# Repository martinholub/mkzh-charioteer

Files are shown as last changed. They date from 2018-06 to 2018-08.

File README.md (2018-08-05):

# CharIoTeer
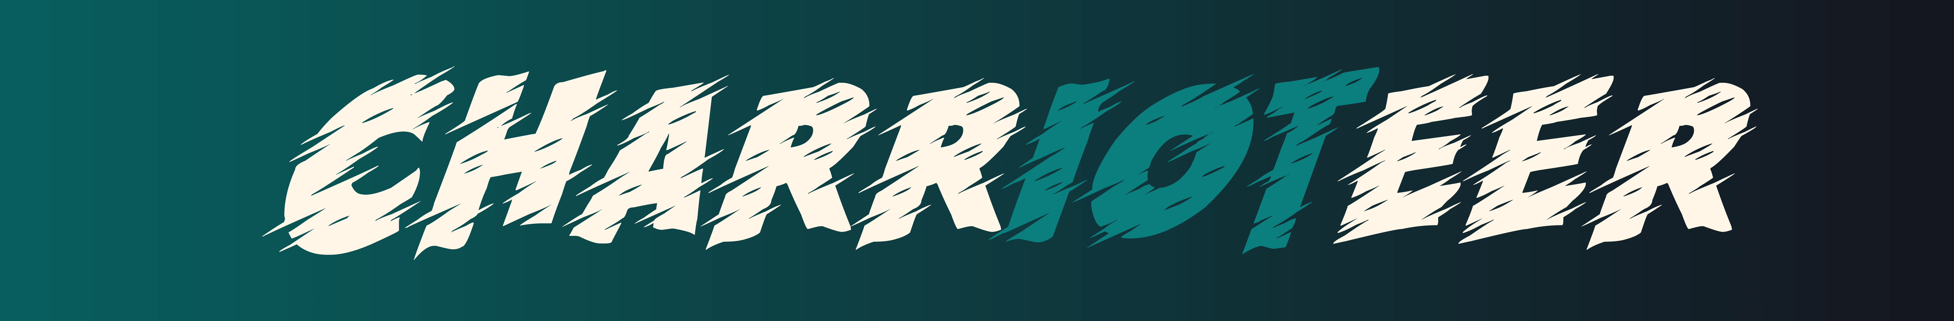
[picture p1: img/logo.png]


### Smart last-mile delivery project @MakeZurich

CharIoTeer is a contribution to the long-standing quest of making delivery smart. By measuring critical indicators of package health (temperature of goods, ambient temperature, humidity, position) together with geographical coordinates. The project provides real-time actionable data for inner-city logistics of high-value shippments (medicines, blood, valuable documents, groceries, cigars,... ).

Check [my blog post](http://www.martinholub.com/eth/code/2018/08/05/MakeZurich.html) on the project.

<!-- and [the project presentation](https://www.slideshare.net/secret/HptLulsGrX1wgX) (credit [Antonios Kouris](https://www.crunchbase.com/person/antonios-kouris#section-overview)). -->

# Building CharIoTeer

Building CharIoTeer is simple and fun! The following sections take you step by step through the process.

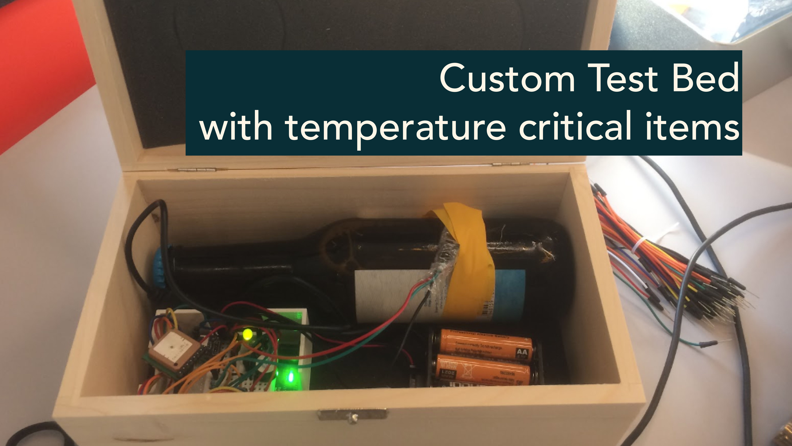
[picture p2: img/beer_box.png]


## Bill of Materials:

* [The Things Network Uno](https://www.thethingsnetwork.org/docs/devices/uno/)
* [ADXL345](https://www.sparkfun.com/datasheets/Sensors/Accelerometer/ADXL345.pdf) Accelerometer
  * alternatively simple [tilt switch](https://learn.adafruit.com/tilt-sensor/using-a-tilt-sensor) may be enough
* [DHT11](http://www.circuitbasics.com/how-to-set-up-the-dht11-humidity-sensor-on-an-arduino/) Temperature and Humidity Sensor
* [Sensirion SHTxx](https://github.com/rac2030/MakeZurich/wiki/SHT31) Temperature and Humidity Sensor
  * alternatively plain [thermistor](http://www.circuitbasics.com/arduino-thermistor-temperature-sensor-tutorial/) will do
* [u-blox PAM-7Q](https://www.u-blox.com/sites/default/files/PAM-7Q_DataSheet_(UBX-13002455).pdf) GPS sensor
* Buzzer, LEDs, Resistors, Jumper Wires, Breadboard, Battery Power Supply
* PLA for 3D printed casing

## Getting Started

Before starting the project, check that your area has [loRaWAN coverage](https://www.thethingsnetwork.org/map). Consider [joining the movement](https://www.thethingsnetwork.org/community) and [building your very own gateway](https://github.com/ttn-zh/ic880a-gateway/wiki). Do some [quick reading](https://www.thethingsnetwork.org/docs/lorawan/) on how LoRaWAN works.

Once your hardware arrives, put it all together:

## Wiring the Arduino

*Note that despite being named The Things Network UNO (TTN Uno), the board is actually a Arduino Leonardo (with a [RN2483](https://www.microchip.com/wwwproducts/en/RN2483) chip). To make this clear, I name TTN Uno TTN Leanardo instead.*

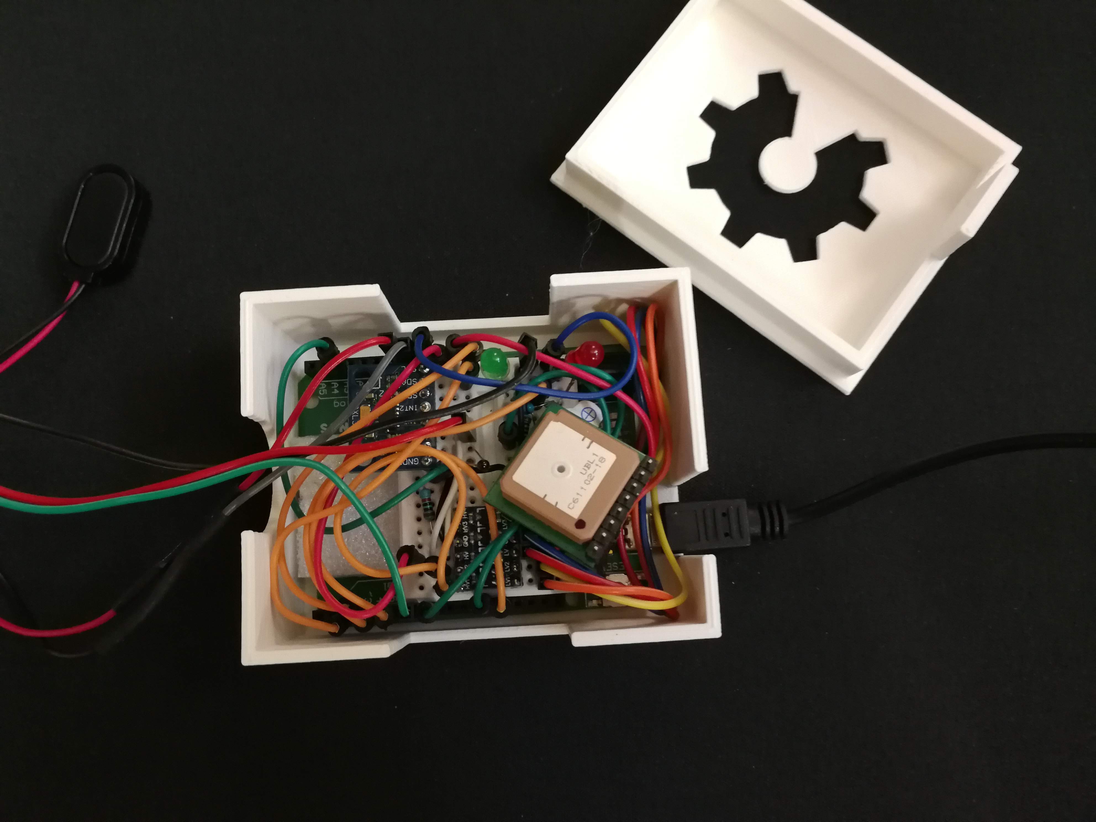
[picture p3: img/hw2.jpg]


**ADXL345** | Arduino UNO | TTN Leonardo
:---:|:---:|:---:
GND | GND | GND
VCC | 5V | 5V
CS | 5V | 5V
SDA | A4 | 2
SCL | A5 | 3

**DHT-11** | Arduino UNO (or TTN Leonardo)
:---:|:---:
\+ | 5V
\- | GND
S | 7

<!---
US100 | Arduino UNO + TTN Leonardo
:---:|:---:
VCC | 5V
GND | GND
Echo | 11
Trig | 10
-->

**u-blox PAM-7Q** | LevelConv | Arduino UNO (or TTN Leonardo)
:---:|:---:|:---:
not connected | HV | 5V
VCC | LV | 3.3V on TTN UNO
TX | LVx <-> HVx | 5
RX | LVx <-> HVx | 13

Device | (+) to board | (-) to board
:---:|:---:|:---:
**red led** | 4 trhu 220R | GND
**green led** | 8 thru 220R | GND
**active buzzer** | 12 | GND thru 100R
**themistor** | 5V | GND thru 10kR and A3

*All connections are identical for Arduino Uno and TTN Leonardo. Polarity for thermistor does not matter.*

## Understanding the Code

#### Practical
You are encouraged to develop the code in [PlatformioIO](https://platformio.org/). If you do so, check the project file `platformio.ini` and make sure it corresponds to your setup. It will handle library dependencies for you. If you are using other IDE (like [Arduino IDE](https://www.arduino.cc/en/Main/Software?)), you may need to install the libraries manually.

#### Sending Data as Bytes

LoRaWAN is a technology that is designed for small volume of transferred data. Each message sent from a device over gateway to a backend is limited to maximally 51 bytes. Preferentially, messages should not exceed 12 bytes as more data per transfer results in longer airtime of each message. Daily airtime per device is limited (see [[limitations](https://www.thethingsnetwork.org/docs/lorawan/limitations.html)] and [[fair access policy](https://www.thethingsnetwork.org/forum/t/limitations-data-rate-packet-size-30-seconds-uplink-and-10-messages-downlink-per-day-fair-access-policy/1300)], therefore messages should not be sent more frequently then every couple of minutes or less.

To reduce the amount of data being sent, I encode each message emitted by the device as bytes. The message is then decoded in a server application by applying reverse mathematical operations.

For example, encoding gographical coordinates to 3 bytes per longitude and 3 bytes latittude may look like this:

``` cpp
void add_buffer_gps(double lat, double lon){

  // offset by 90(180) to make positive and scale to 0..1
  latB = ((lat + 90) / 180.0) * pow(256,3);
  lonB = ((lon + 180) / 360.0) * pow(256,3);

  // byte shifting
  dataBuffer[0] = ( latB >> 16 ) & 0xFF;
  dataBuffer[1] = ( latB >> 8 ) & 0xFF;
  dataBuffer[2] = latB & 0xFF;

  dataBuffer[3] = ( lonB >> 16 ) & 0xFF;
  dataBuffer[4] = ( lonB >> 8 ) & 0xFF;
  dataBuffer[5] = lonB & 0xFF;
  }
```

Another example is encoding of tilt of the device as measured by accelerometer:

``` cpp
void add_buffer_tilt(float Xg_crit, float Yg_crit, int it = 0) {
  // it, position where to start writing to the buffer

  // offset by 2 to assure range -1..1 becomes positive and scale to 0..1
  XgB = (Xg_crit  + 2.0) * pow(256,1) / 4;
  YgB = (Yg_crit + 2.0) * pow(256,1) / 4;

  // each value is just one byte
  dataBuffer[it] = XgB;
  dataBuffer[it+1] = YgB;
  }
```

#### Using Rolling Averages

I want to send message every couple of minutes but our Aurdino with sensors is capable of collecting data at much higher rate. It is advantaegous to send values averaged over several preceding measurements. This makes our measurements more accurate and helps to deal with outliying values. For example for humidity I do that as follows:

``` cpp
#include <RunningAverage.h>
#include <dht11.h> // temperature and humidity sensor
RunningAverage myRA_h(10); // 10 is size of buffer
void setup(){
  myRA_h.clear();
  }

void loop(){
  // ...
  myRA_h.addValue((float)DHT11.humidity);
  // ...
  }
```
#### Obtaining GPS Data

Check out the [working example](https://gitlab.com/mkzh-milesahead/arduino-gps) developed by @njam.

##### Using Smart Delay and Software Serial

The Arduino hardware has built-in support for serial communication on pins 0 and 1 (which also goes to the computer via the USB connection). The native serial support happens via a piece of hardware (built into the chip) called a UART. The Software Serial is used to allow serial communication on other digital pins of the Arduino,

```cpp
static const int RXPin = 13, TXPin = 5;
AltSoftSerial gpsSerial(RXPin, TXPin);

void delay_smart(unsigned long ms) {
  // This custom version of delay() ensures that the gps object is "fed"
  unsigned long start = millis(); // Get current time from board start in ms
  do {
    // wait for data available
    while (gpsSerial.available()) {
      gps.encode(gpsSerial.read());
    }
    // wait extra if needed to fill delay
  } while (millis() - start < ms);
}
```

#### Talking with The Things Network

```cpp
#include <TheThingsNetwork.h>
#include <private_keys.h> // imports appKey and appEUI from external file

#define loraSerial Serial1
#define freqPlan TTN_FP_EU868 // Use european freq plan
#define COUNT_OF(array) (sizeof(array) / sizeof(array[0])) // gets array size

TheThingsNetwork ttn(loraSerial, Serial, freqPlan);
bool is_connected = false;
uint8_t dataBuffer[12] = {0}; // uint8_t is byte, buffer can hold 12 bytes

void send_ttn_message(uint8_t* data, size_t data_size, port_t prt = 1) {
    if(is_connected){
      ttn.sendBytes(data, data_size);// sizeof(data)
    } else {
      Serial.print("ttn message: ");
      uint8_t i = 0;
      for (i = 0; i < data_size; i++){ // prints byte message in HEX encoding
        if (data[i] < 16) {
          Serial.print("0");
          Serial.print(data[i], HEX);
        } else {
          Serial.print(data[i], HEX);
        }
      }
      Serial.println("");
    }
}

void setup(){
  Serial.print("--- TTN STATUS ---"); ttn.showStatus();
  ttn.provision(appEui, appKey);
  is_connected = ttn.join(10); // try to connect up to 10 times
  if (!is_connected){
    Serial.print("Join to TTN failed.");
  }
}

void loop(){
  // ...
  // Messaging the TTN Application
  if (iteration % send_per == 0){ // send only infrequently
    send_ttn_message(dataBuffer, COUNT_OF(dataBuffer));
  }
  // ...
}
```

More can be found on the [Quick Start](https://www.thethingsnetwork.org/docs/devices/uno/quick-start.html) site for the TTN Uno (Leonardo) device.

## Printing the Case

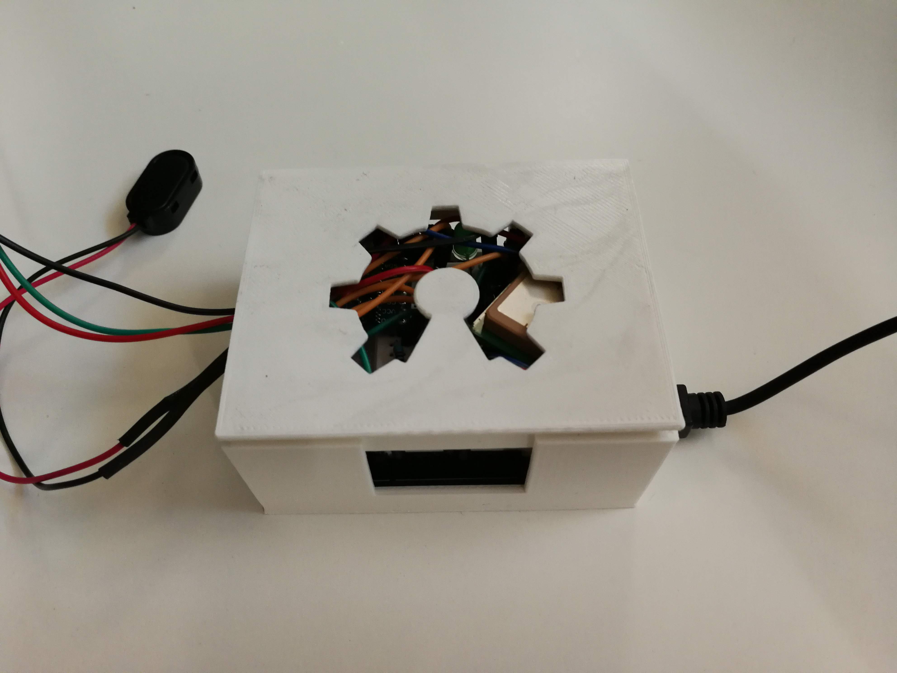
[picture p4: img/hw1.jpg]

I wanted to have a nice casing for the project to work as tight protective enclosure and to make it all together look neat. To design the case (starting from a [template](https://www.thingiverse.com/thing:78032)) I used [OpenSCAD](http://www.openscad.org/). I sliced the `stl` files to `gcode` using [CURA](https://ultimaker.com/en/products/ultimaker-cura-software) and printed them on a 3D printer from [Teil3](https://www.teil3.ch/shop/3d-drucker.html). You will find the design in `scad` file in `hw` folder for you to adjust and play with.

<!-- mail guy from tel3d ..... get cura settings! -->

## Receiving and Decoding Payloads

Once the data was emitted by the [RN2483](https://www.microchip.com/wwwproducts/en/RN2483) chip, received by usually [multiple](https://www.thethingsnetwork.org/docs/network/architecture.html#de-duplication-broker)) gateways it is handed over to the backend server application. We used [The Things Network Console](https://console.thethingsnetwork.org/) to create and manage such applciation inlcuding its `decoder` , `validator` and `converter` functions.

For example the `decoder` function for geographical coordinates and for temperature looks as following (compare with encoding on Arduino above):

```js

function Decoder (bytes, port) {
  var decoded = {}
  if (port === 1) {
    if (bytes.length === 10) {
      var lat = bytesToInt(bytes.slice(0, 3)) / Math.pow(256, 3) * 180 - 90
      var lon = bytesToInt(bytes.slice(3, 6)) / Math.pow(256, 3) * 360 - 180
      if (lat !== 0 && lon !== 0) {
        decoded['lat'] = lat
        decoded['lon'] = lon
      }

      var tiltx = bytesToInt(bytes.slice(10, 11)) / Math.pow(256, 1) * 4 - 2
      decoded['tiltx'] = tiltx
      var tilty = bytesToInt(bytes.slice(11, 12)) / Math.pow(256, 1) * 4 - 2
      decoded['tilty'] = tilty
    }
  }
  return decoded
}

function bytesToInt (bytes) {
  var integer = 0
  for (var n = 0; n < bytes.length; n++) {
    integer += bytes[n]
    if (n < bytes.length - 1) {
      integer = integer << 8
    }
  }
  return integer
}
```

Here is a sample of datapoint:

```json
{"_id": "5b377f54e4d28c0006c1ab93",
  "deviceId":"ttn-uno",
  "receivedAt":"2018-06-30T13:02:12.565Z",
  "metadata":{
    "time":"2018-06-30T13:02:12.339076452Z",
    "frequency":868.1,
    "modulation":"LORA",
    "data_rate":"SF7BW125",
    "airtime":66816000,
    "coding_rate":"4/5",
    "gateways":[
      {"gtw_id":"eui-0000024b080310b1",
        "timestamp":628068507,
        "time":"2018-06-30T13:02:11.414067Z",
        "channel":0,
        "rssi":-117,
        "snr":1.5,
        "rf_chain":1,
        "latitude":47.37787,
        "longitude":8.53909,
        "altitude":433
      }
    ]
  },
  "dist":0,
  "speed":0,
  "temp-inside":16.99981689453125,
  "temp-outside":23.09722900390625,
  "tiltx":0.1875,
  "tilty":-0.203125
}
```
## Storing and Visualizing Data

The server application was developed by [@njam](https://github.com/njam). The full source code is available at the [project's gitlab](https://gitlab.com/mkzh-milesahead/ttn-milesahead). The visalizations are available [here](https://ttn-milesahead.herokuapp.com/).

Here is a sample visualization showing geographical coordinates as dots color-coded by temperature measured by DHT11 sensor.

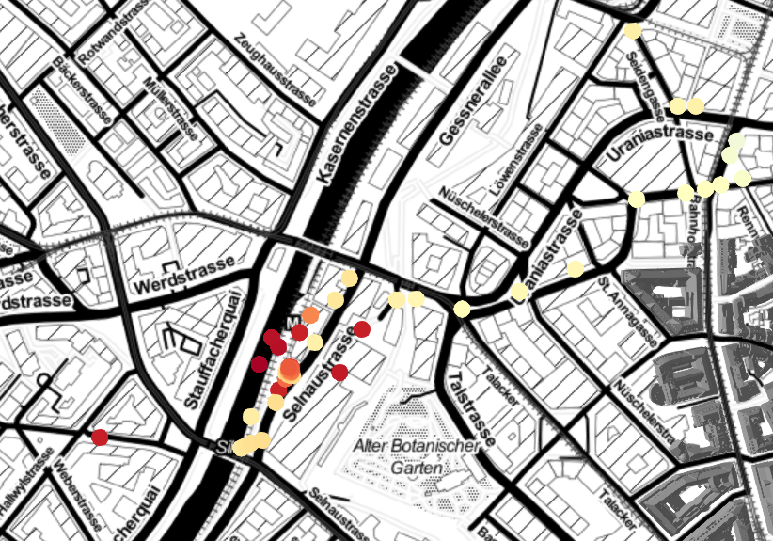
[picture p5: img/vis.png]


## Remarks
* If you decide to use SHTxx sensor together with ADXL345 acceloremeter, you will have them share I2C bus. This is [not a problem](https://www.bluedot.space/tutorials/how-many-devices-can-you-connect-on-i2c-bus/) as long as the devices will [have dfferent addresses](http://www.learningaboutelectronics.com/Articles/Multiple-I2C-devices-to-an-arduino-microcontroller.php).
* If you want to deploy the device for real-world application, consider using LoRa capable low-power microcontroller like [MSP430](https://platformio.org/lib/show/374/armapi), [muRata LoRaWan module](https://www.murata.com/en-sg/products/lpwa/lora) or [MKR WAN 1300](https://store.arduino.cc/mkr-wan-1300)

## References
* [MakeZürich](https://makezurich.ch/about/)
* [The Things Network Community in Zürich](https://www.thethingsnetwork.org/community/zurich/)
* [Post kauft Logistik Startup notime](https://www.startupticker.ch/en/news/march-2018/post-kauft-logistik-startup-notime) (German)

## Team
* Martin Holub ([web](http://www.martinholub.com/about/))
* Reto Kaiser ([@njam](https://github.com/njam))
* Antonios Kouris ([crunchbase](https://www.crunchbase.com/person/antonios-kouris#section-overview))
* Charilaos ([@tsarouch](https://github.com/tsarouch))

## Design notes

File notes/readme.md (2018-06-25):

# Follow-up notes for meeting #1

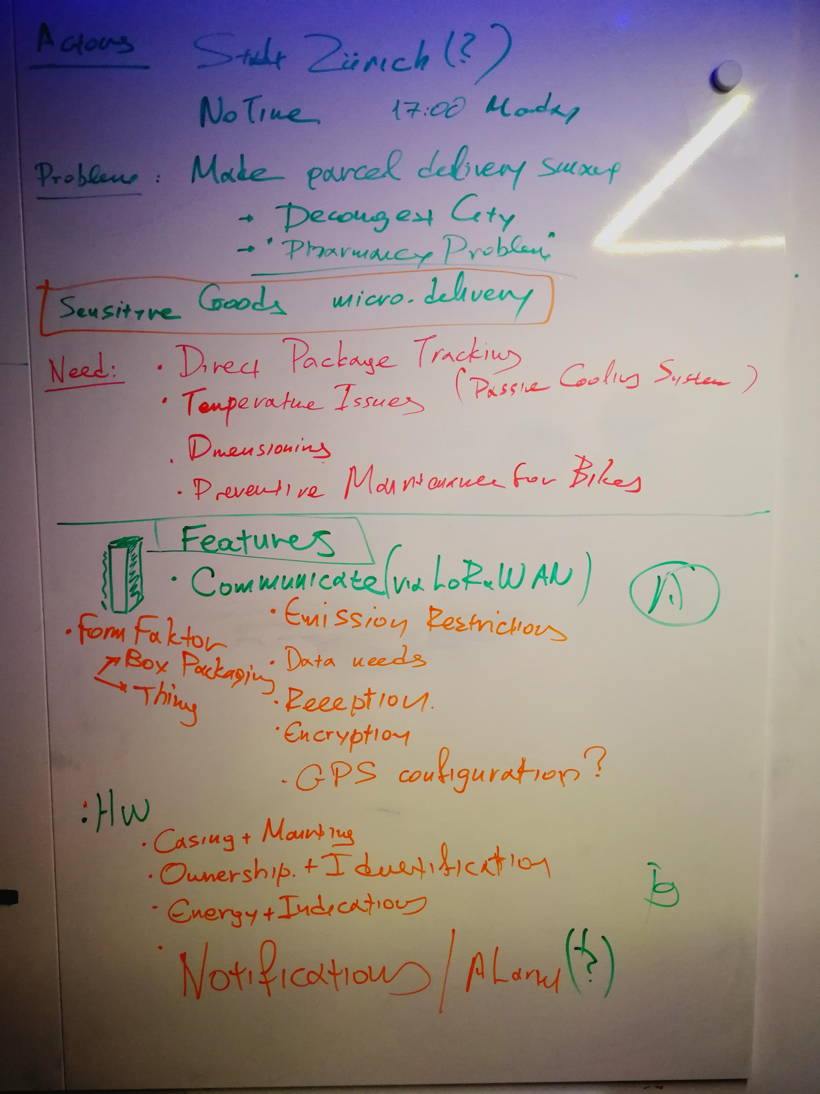
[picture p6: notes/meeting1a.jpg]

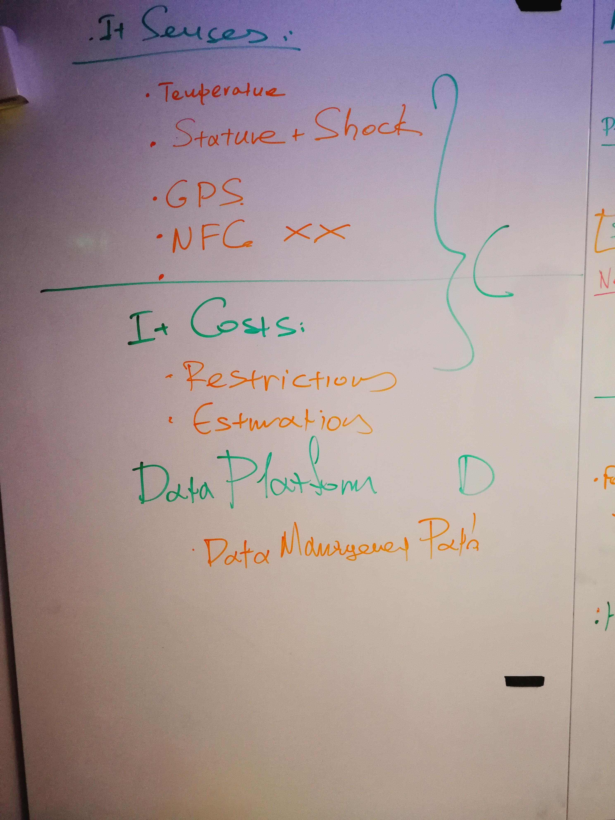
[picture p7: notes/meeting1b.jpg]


# Features

## Communication (Martin)

TODO: suck out info from here: https://www.thethingsnetwork.org/docs/lorawan/

#### Requirements
Note: sensors have errors - can [round](https://www.thethingsnetwork.org/docs/devices/bytes.html#2-round) and save on data transmission
+ Tilt: 
  + 1/0 ... Ok/Bad
  + 0.xx for X and Y axes -> 2 bytes
+ Temp:
  + 1/0 ... Ok/Bad
  + xx.x ... float with 1 decimal -> 1 byte (?)
+ Humidity:
  + 1/0 ... Ok/Bad -> 1 bit
  + xx %  -> 1 byte
+ US sensor:
  + xx for 3 axes -> 3 bytes
+ [GPS coords](https://www.thethingsnetwork.org/forum/t/best-practices-when-sending-gps-location-data/1242):
  + see the link for detailed limitations and tips

#### Limitations
+ [Limitations](https://www.thethingsnetwork.org/docs/lorawan/limitations.html)

[Limitations: data rate, packet size, 30 seconds uplink and 10 messages downlink per day Fair Access Policy](https://www.thethingsnetwork.org/forum/t/limitations-data-rate-packet-size-30-seconds-uplink-and-10-messages-downlink-per-day-fair-access-policy/1300)
  + 30 seconds air-time per device per day. For 10 bytes of payload, this translates in (approx.):
    + 20 messages per day at SF12
    + 500 messages per day at SF7
  + Downlink bandwidth is even more restricted (10 msg per day) = you can’t send all messages as ‘confirmed uplink’
  - Payload should be as small as possible. A good goal is to keep it under 12 bytes. ...
  - Interval between messages should be in the range of several minutes, ...
If your application requires more bandwidth, think of another solution
  + In short LoRa excels at rare and small messages from a device that can live independetly for years. Does this fit our application?
  
#### The Network
> Each transmission blocks the receivers of a gateway for some time, it is better to send messages in a shorter time [source](https://www.thethingsnetwork.org/docs/network/architecture.html#downlink-configuration-router).

> LoRaWAN is a long-range radio protocol, making it likely that the message is received by more than one gateway [source](https://www.thethingsnetwork.org/docs/network/architecture.html#de-duplication-broker). Backend then must perform some de-duplication to obtain unique message. The information from duplictaes can be used to get location of the emitting device. Required de-duplication time is about 200ms.

> The frame counter in LoRaWAN messages is a security measure used to detect replay attacks. After validating the MIC, the Broker checks if the Frame counter is valid. As frame counters can only increase, a message with a frame counter that is lower than the last known frame counter should be dropped. [sourcce](https://www.thethingsnetwork.org/docs/network/architecture.html#frame-counter-check-broker)

`decoder`, `converter`, `validator` functions are used [to interpret](https://www.thethingsnetwork.org/docs/network/architecture.html#payload-conversion-handler) message on the handler side.

#### Security
> LoRaWAN enforces using AES 128-bit message integrity checks and payload encryption. Payloads are fully encrypted between the Node and the Handler component of the backend. This means you can choose to operate your own private Handler and have real end-to-end encryption. [source](https://www.thethingsnetwork.org/docs/network/security.html). The metadata is not encrypted.

#### Devices

> Technically, you can send 51 bytes. But, the more bytes you’ll send, the more airtime the package will cost you. [source](https://www.thethingsnetwork.org/docs/devices/bytes.html#how-many-bytes-can-i-send)

[How to send decimals?](https://www.thethingsnetwork.org/docs/devices/bytes.html#how-to-send-decimals)
[How to send multiple numbers?](https://www.thethingsnetwork.org/docs/devices/bytes.html#how-to-send-multiple-numbers)
[How to send big numbers?](https://www.thethingsnetwork.org/docs/devices/bytes.html#how-to-send-big-numbers)
How to send text? The short answer is: don’t.

> Devices should perform join operations the less possible in their lifetime. The LoRaWAN specifications warn especially against systematic rejoin in case of network failure. A device should keep the result of an activation in permanent storage if the device is expected to be turned off during its lifetime. [source](https://www.thethingsnetwork.org/docs/devices/bestpractices.html#otaa-best-practices)

#### Practical Bits and Pieces

Transmitted data:
  + Can get [some metadata](https://www.thethingsnetwork.org/docs/network/architecture.html#gateway-protocol-translation-routerbridge) from gateway message:
    + signal strength (RSSI) and signal-to-noise ratio (SNR)
  + Message has "port" field. Can use to switch between incoming measurements

+ Neither LoRa nor GPS will be able to communicate from a box
  + already indoor coverage is a problem
  + we may want to prototype from inside a box?
  + No guarantee on acceptance of message

+ Should be able to switch network providers
  + e.g. tnn > fallback to loriot > fallback to swisscom
  + provider may limit number of messages (Swisscom... 10/day)
  + this may be possible from platform.makezurich.ch
  
### Questions
+ Can GPS talk from a box? Where it needs to be?
+ What sensors does the FMLR TrackerTwo have?
+ How often do we need to transmit data? How often we can? (LoRaWAN)

### References:

[TTN-Learn-Network](https://www.thethingsnetwork.org/docs/network/architecture.html)

## Hardware (Reto)

### Accelerometer
https://learn.adafruit.com/adafruit-bno055-absolute-orientation-sensor?view=all
https://www.aliexpress.com/item/BNO055-CJMCU-055-Intelligent-9-Axis-Attitude-Sensor-precision-Accelerometer-gyroscope-magnetic-sensor-module-for-arduino/32842626275.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
https://www.allaboutcircuits.com/projects/bosch-absolute-orientation-sensor-bno055/
https://www.davidpilling.com/wiki/index.php/BNO055

#### Notes
To solder or not to solder [the barrel](https://forums.adafruit.com/viewtopic.php?f=19&t=118110)
> The object resembling a tilt switch is probably a 32.768 kHz quartz crystal. It's optional. You can send a command to the BNO telling it to use either its lower-accuracy internal oscillator, or its higher-accuracy crystal oscillator.

SDA/SCL pins on [Leonardo and Uno](https://arduino.stackexchange.com/a/160)

https://learn.adafruit.com/adxl345-digital-accelerometer/programming

## Sensing (Antonias)

## Dataplatform (Charilaos)

console.thethingsnetwork.org
platform.makezurich.ch

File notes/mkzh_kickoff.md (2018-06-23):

# Real Time Occupancy Rate
Real time data on all vehicles (bus, trams, boats?)
# City forest visitiors
Lot of entry points to big area
No concrete idea how many people come in
- Where people tend to stay/linger
- Which roads are used more / is there more roads? Trend detection
- Conflict detection
- Resources allocation justification
- Mind people/data security!
PubliBike
- No docking station
- Bike is wirelessly connected to the station point
- Lot of bikes lausanne
- Need to track bikes that are left behind, possibly without battery
- Can be unlocked with any RFID card
- Must be easy to install
- Dont use bike battery
- better than 50 m accuracy
- has slack
Coquering the last mile
- not presented
Teachers calling (stakeholder not present)
- Needs to be silent
- Students cant use cellphones, teacher should not be focusing on cellphone
(could use that older people hear at different freq)
- would be nice if the person has some GPS location 
Distribution challenge (ewz)
- power failure at homes --- they cannot see it
- customers must conntact help center
- putting sensor to distribution cabing may be an option.
- only 2000 cabins in ZH (solution should scale/ 100chf per cabin maximum)
- every 10 days there is a power outage ... what about some stats
  - civil engineering work (shoould alert the workers), svere weather
- space is limited

Platfomr provided by HiveMide
  - Some sensors from Sensirion

platfrom.makezurich.ch
now.makezurich.ch
Teil3 ... 3D printers
GoogleDeveloperGroup (Michelle)

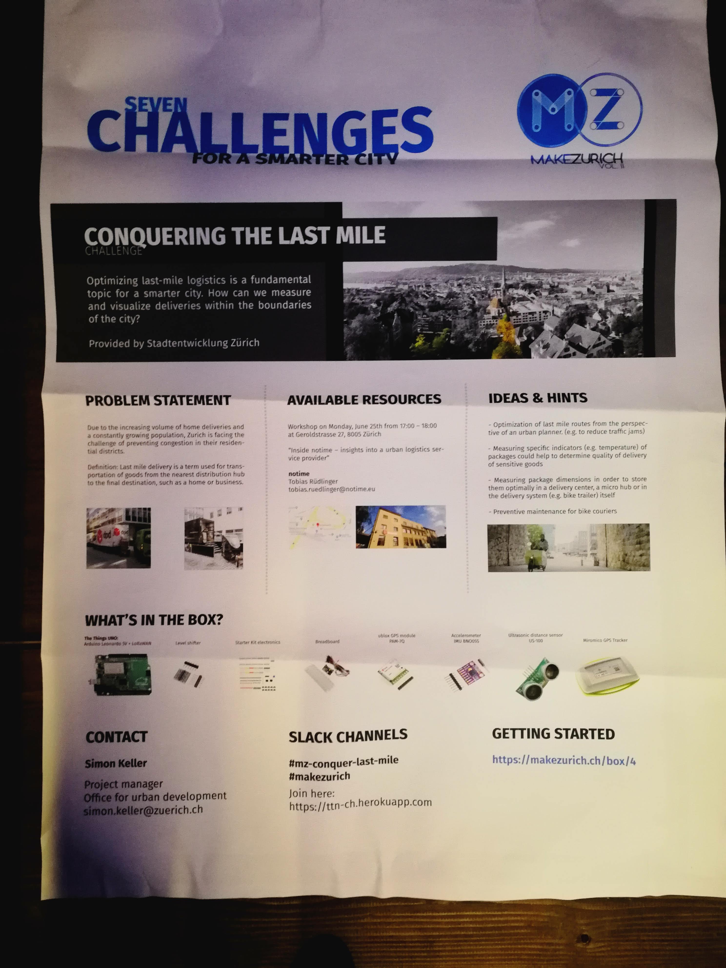
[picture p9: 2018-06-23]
notes/challenge_poster.jpg

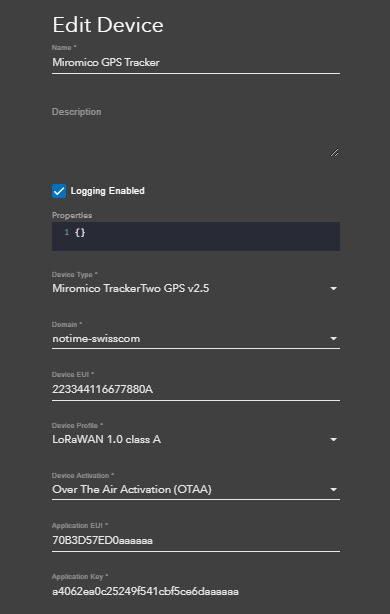
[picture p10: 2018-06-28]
docs/GPSTracker_details.png

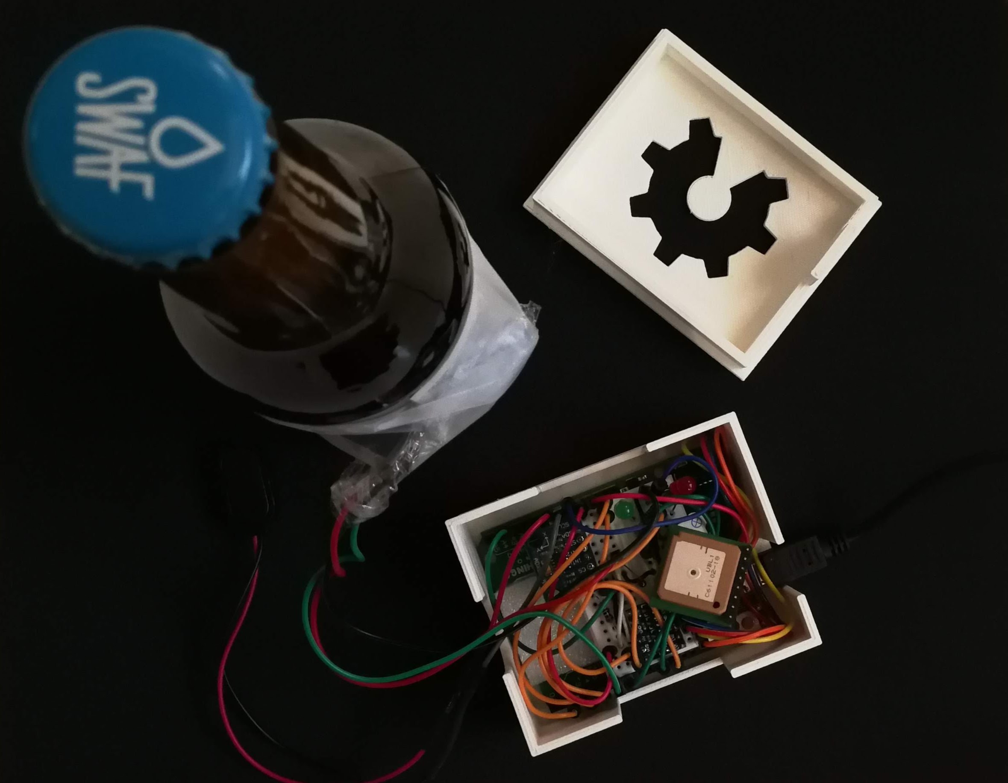
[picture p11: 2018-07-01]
img/hw_and_beer.jpg

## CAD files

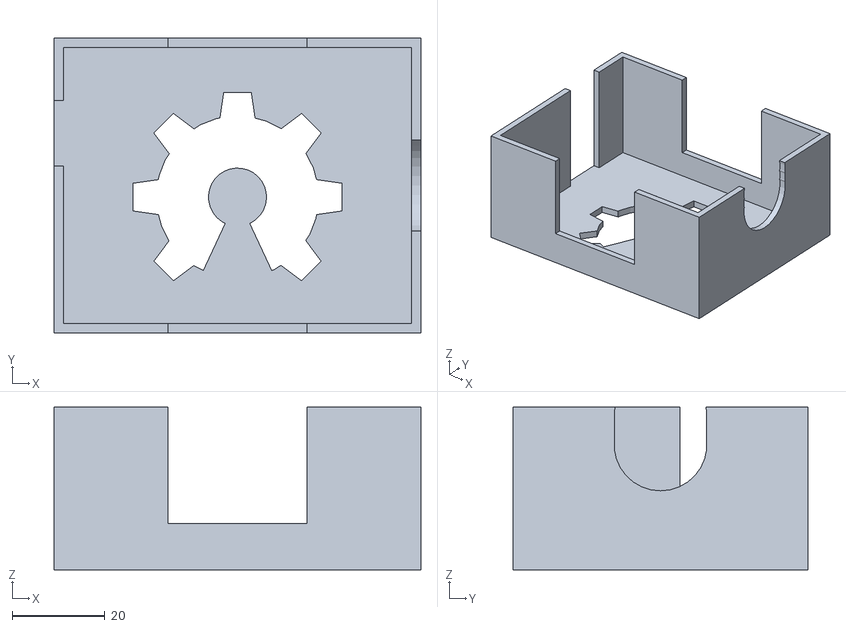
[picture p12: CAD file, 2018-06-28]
hw/arduino_leonardo_box_h35mm_m40mm_v40_notime_boxx.stl
79.0 x 63.5 x 35.0

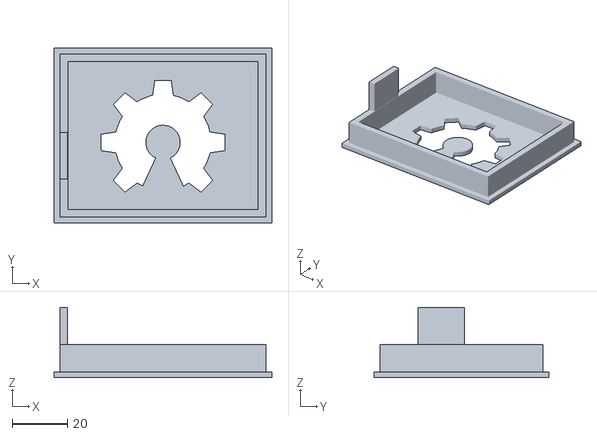
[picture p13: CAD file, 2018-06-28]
hw/arduino_leonardo_box_h35mm_m40mm_v40_notime_deckel.stl
79.0 x 63.5 x 25.5

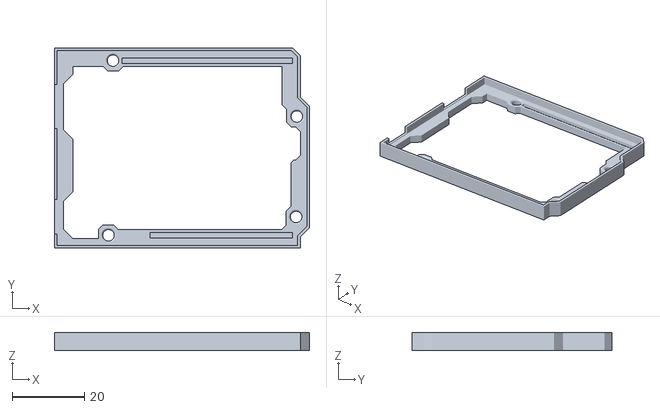
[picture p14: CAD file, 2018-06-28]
hw/bumper.stl
70.5 x 55.2 x 5.08

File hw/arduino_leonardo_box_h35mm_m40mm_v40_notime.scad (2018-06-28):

// Arduino Box with additional space for electronics
// Leonardo form  
//
// V3.1 - little bigger usb hole
// V4.0 reworked, V4.0a correction deckelweite
//
// (C)2013 Nischelwitzer Alexander nischelwitzer@gmail.com
// ----------------------------------------------------------- 

use<write/write.scad>

// ------------------------------------------- breadboard size

card_length = 69.0;
card_width  = 53.5;

// ------------------------------------------- 

box_do      =  0;  // 1 if additional box is used

box_height  = 35;
box_more    = 40;
shifter     = 10;

// ------------------------------------------- 

wall        =  2;
space       =  0.3;
dummy       =  1; // not used

deckel      = 12;

name_it     =  0;  // write some text
form_it     =  0;  // inside form for leonardo

// ------------------------------------------- 
do_light = 1; // print with lot of holes
do_easy = 1; // print w/out any support
// ################################################################
// ################################################################

// translate([0,card_width+shifter-10,0]) deckel();
translate([0,0,0])                     boxx();
translate([0,-(card_width+20),0])      deckel_innen();

// ################################################################
// ################################################################

module boxx() {
  difference() 
  {
    union()  
    {  
      color([1,0,0,1])  translate([0, 0, 0]) 
        cube([card_length+shifter,card_width+shifter,box_height]); 

      color("blue") translate([card_length+shifter-box_do*wall, 0, 0]) 
        cube([box_do*box_more,card_width+shifter,box_height]);
 	}

    translate([wall, wall, wall]) 
      cube([card_length-2*wall+shifter,card_width-2*wall+shifter,box_height]); 
    translate([card_length+shifter+wall-box_do*wall, wall, wall]) 
      cube([box_do*box_more-2*wall,card_width-2*wall+shifter,box_height]); 
   
   // usb connector
   if (do_easy != 1) { // will use support
       translate([-9,36,2]) cube([17,14,10]); 
   } else if (do_easy == 1) { // hole all way to the top to avoid support
       translate([-9,36,2]) cube([17,14,box_height+shifter]);
       }
   

   // connector hole inside
   if (box_do == 1)
   {
     translate([card_length,(card_width+shifter)/2,box_height-deckel/2]) 
       rotate([0,90,0]) cylinder(r=17,h=20);  
     translate([card_length,wall,box_height-deckel-2]) 
       cube([20,card_width+shifter-2*wall,deckel*2]);
   }

   // connector hole outside
   for (a =[8,5,2]){ // repeat couple of times to get nice transition
       translate([card_length+box_do*box_more,(card_width+shifter)/2,box_height-a]) 
     rotate([0,90,0]) cylinder(r=10,h=20); 
       }
    
   // pefuse with holes where possible
   if (do_light == 1) {
       // Add rectangular "windows" on sides
       c_x = 30;
       c_y = 1/3 * c_x;
       c_z = c_x;
       translate([card_length/2-c_x/2 + shifter/2,-c_y/2,box_height/2-c_z/4]) cube([c_x,c_y,c_z]);
       translate([card_length/2-c_x/2 + shifter/2,card_width+shifter/2-c_y/2 + shifter/2,box_height/2-c_z/4]) cube([c_x,c_y,c_z]);
       
       // Add same connector hole also on front side
       if (do_easy != 1){ // Don't over do it and avoid collision of shapes
           for (a =[8,5,2]){
           translate([-shifter,(card_width+shifter)/2,box_height-a])
           rotate([0,90,0]) cylinder(r=10,h=20); 
           }
       }
   
       // logo open hardware
       translate([(card_length+box_do*box_more)/2+shifter/2,(card_width+shifter/2)/2, -10]) rotate([0,0,0]) 
       linear_extrude(height=20) import(file="./oshw_logo_2d.dxf", scale=0.25);
   }
   }
  if (form_it == 1) // Include board holder
  translate([card_length/2+shifter/2,card_width/2+shifter/2,wall])  
    import("bumper.stl");
}


// ################################################################

module deckel() {
   // not used
  difference() 
  {
    union()  
    {   
      color([0,1,0,1])  translate([0-wall-space, shifter*2-wall-space, 0]) 
        cube([card_length+shifter+box_do*box_more+2*(wall+space)-box_do*wall,
              card_width+shifter+2*(wall+space),deckel]); 
	}

    translate([0-space, shifter*2-space, wall]) 
      cube([card_length+shifter+box_do*box_more+space*2-box_do*wall,
            card_width+shifter+space*2,deckel]); 
  }

  if (name_it == 1) translate([wall*4, wall*4+shifter*2, wall]) rotate([0,0,0]) 
    write("Nischelwitzer",t=2,h=8.0,center=false,font="letters.dxf");
}

// ################################################################

module deckel_innen() 
{
  difference() 
  {
    union()  
    {   
      color([0,1,1,1]) translate([0, 0, 0]) 
      cube([card_length+shifter+box_do*box_more-box_do*wall,
            card_width+shifter,wall]); 

      color([0,0,1,1]) translate([wall+space/2,wall+space/2, 0]) 
      cube([card_length+shifter+box_do*box_more-space-2*wall-box_do*wall,
           card_width+shifter-space-2*wall,deckel]);
    
    // Create overlap from top to hide some of insides
    if (do_easy==1){
        mltplier = 1.2;
        color([0,0,1,1]) translate([wall+space/2,card_width+-(1-mltplier)*14-36-space-2*wall,2]) cube([wall+2.5*space,mltplier*14,2*wall+deckel+box_height/2-10]);
        }
	}
    // Create rim by substracting inner cube
    translate([2.5*wall, 2.5*wall, wall])
      cube([card_length+shifter+box_do*box_more-5.0*wall-box_do*wall,
            card_width+shifter-5*wall, deckel]);
    
    // logo open hardware
    // pos mitte
    translate([(card_length+box_do*box_more)/2+shifter/2, (card_width+shifter/2+shifter*name_it)/2, -10]) rotate([0,0,0]) 
    linear_extrude(height=20) import(file="./oshw_logo_2d.dxf", scale=0.25);
    
    // pos over leonardo
    // translate([(card_length+box_do*box_more)/2+shifter/2-30, 0, -10]) rotate([0,0,0]) 
    //   linear_extrude(height=20) import(file="./oshw_logo_2d.dxf", scale=0.3);
  }

  if (name_it == 1) // write name on the inside of the deckel
  translate([wall*4, wall*4, wall]) rotate([0,0,0]) 
    write("milesahead",t=2,h=9.0,center=false,font="letters.dxf");
  // outside would be also nice but difficult to print
}
// ################################################################

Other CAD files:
hw/oshw_logo_2d.dxf

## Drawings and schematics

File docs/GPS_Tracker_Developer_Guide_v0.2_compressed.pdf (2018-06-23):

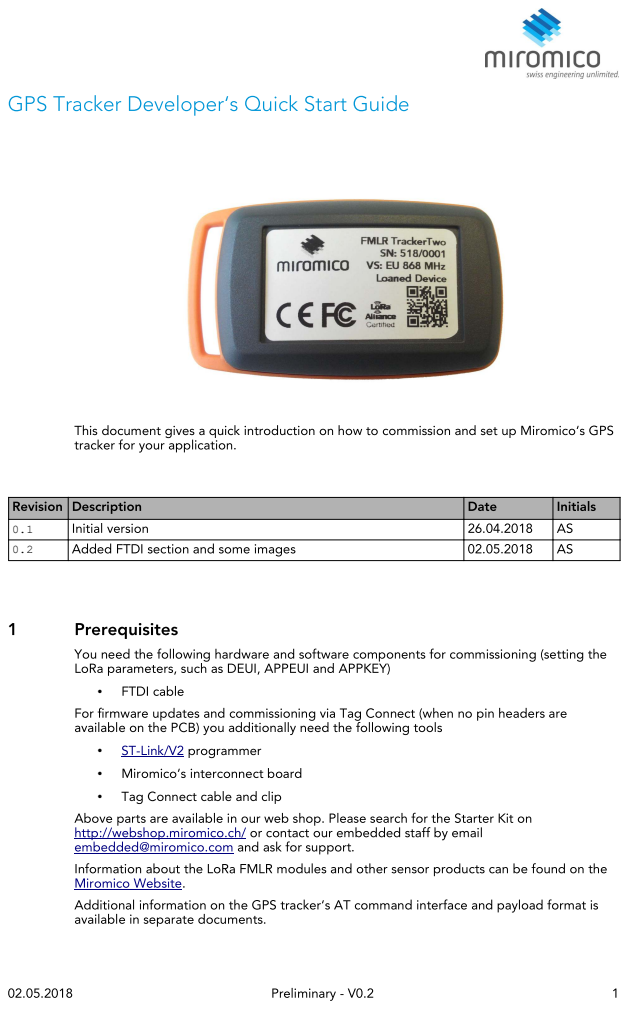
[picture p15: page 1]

0.1
0.2

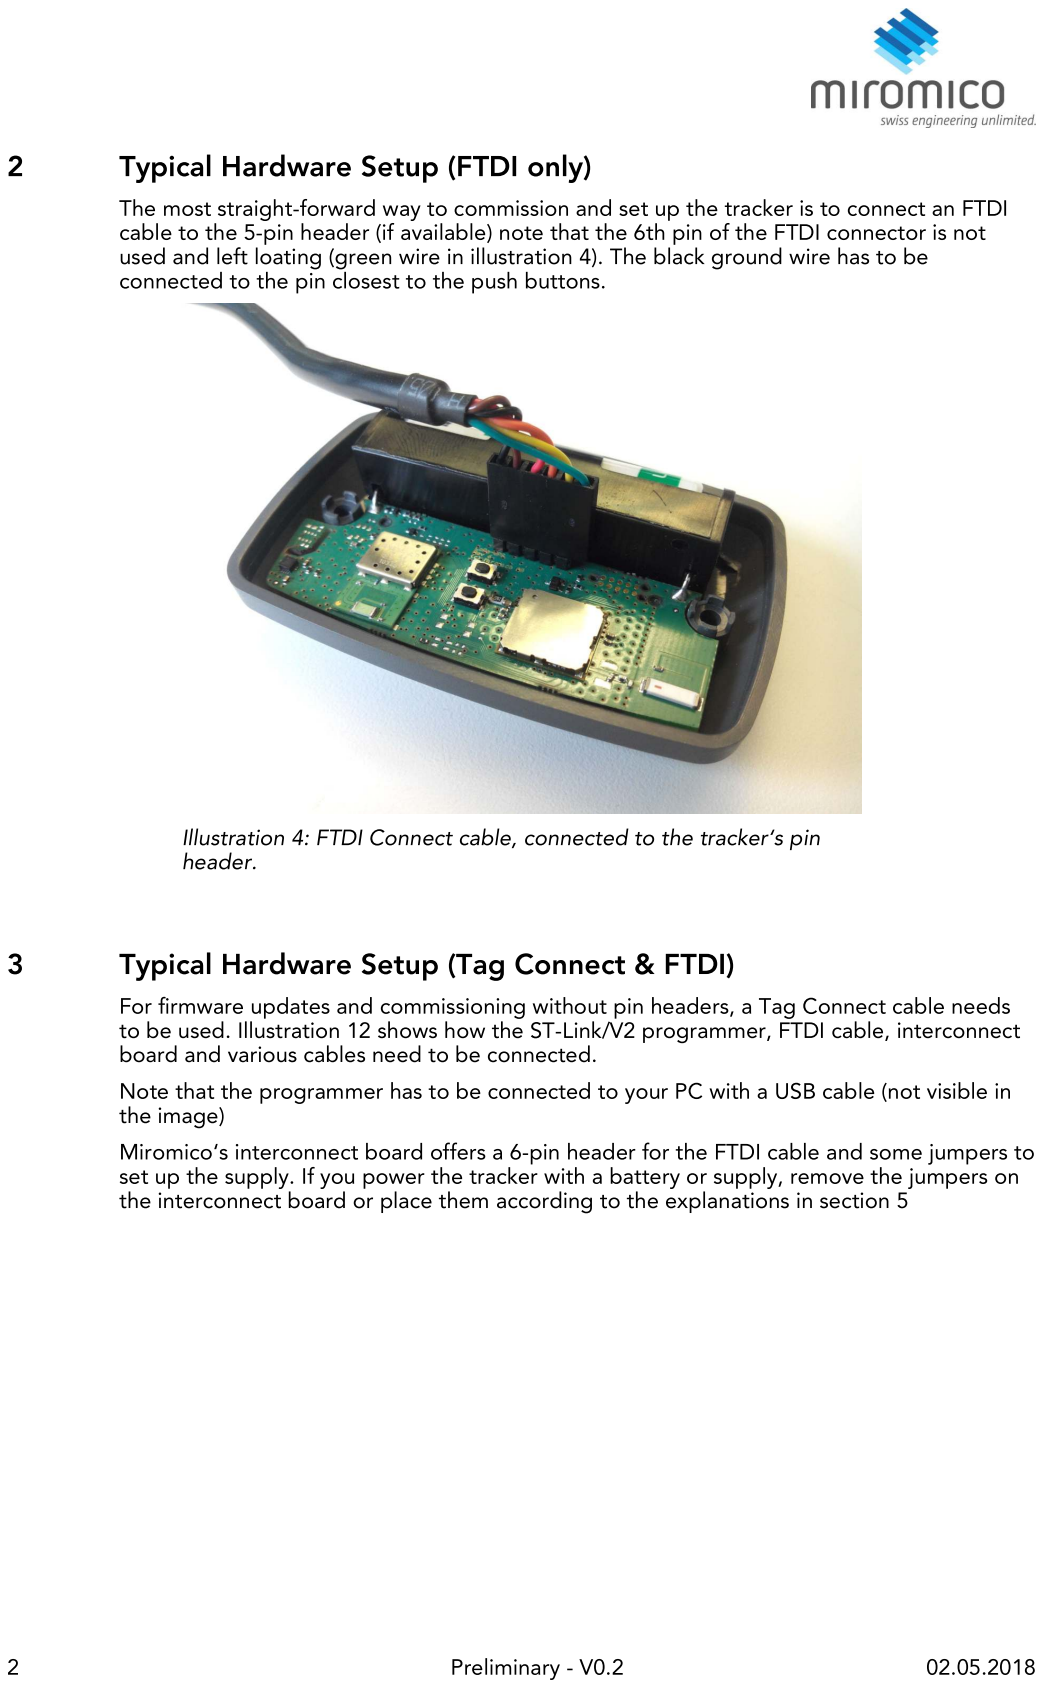
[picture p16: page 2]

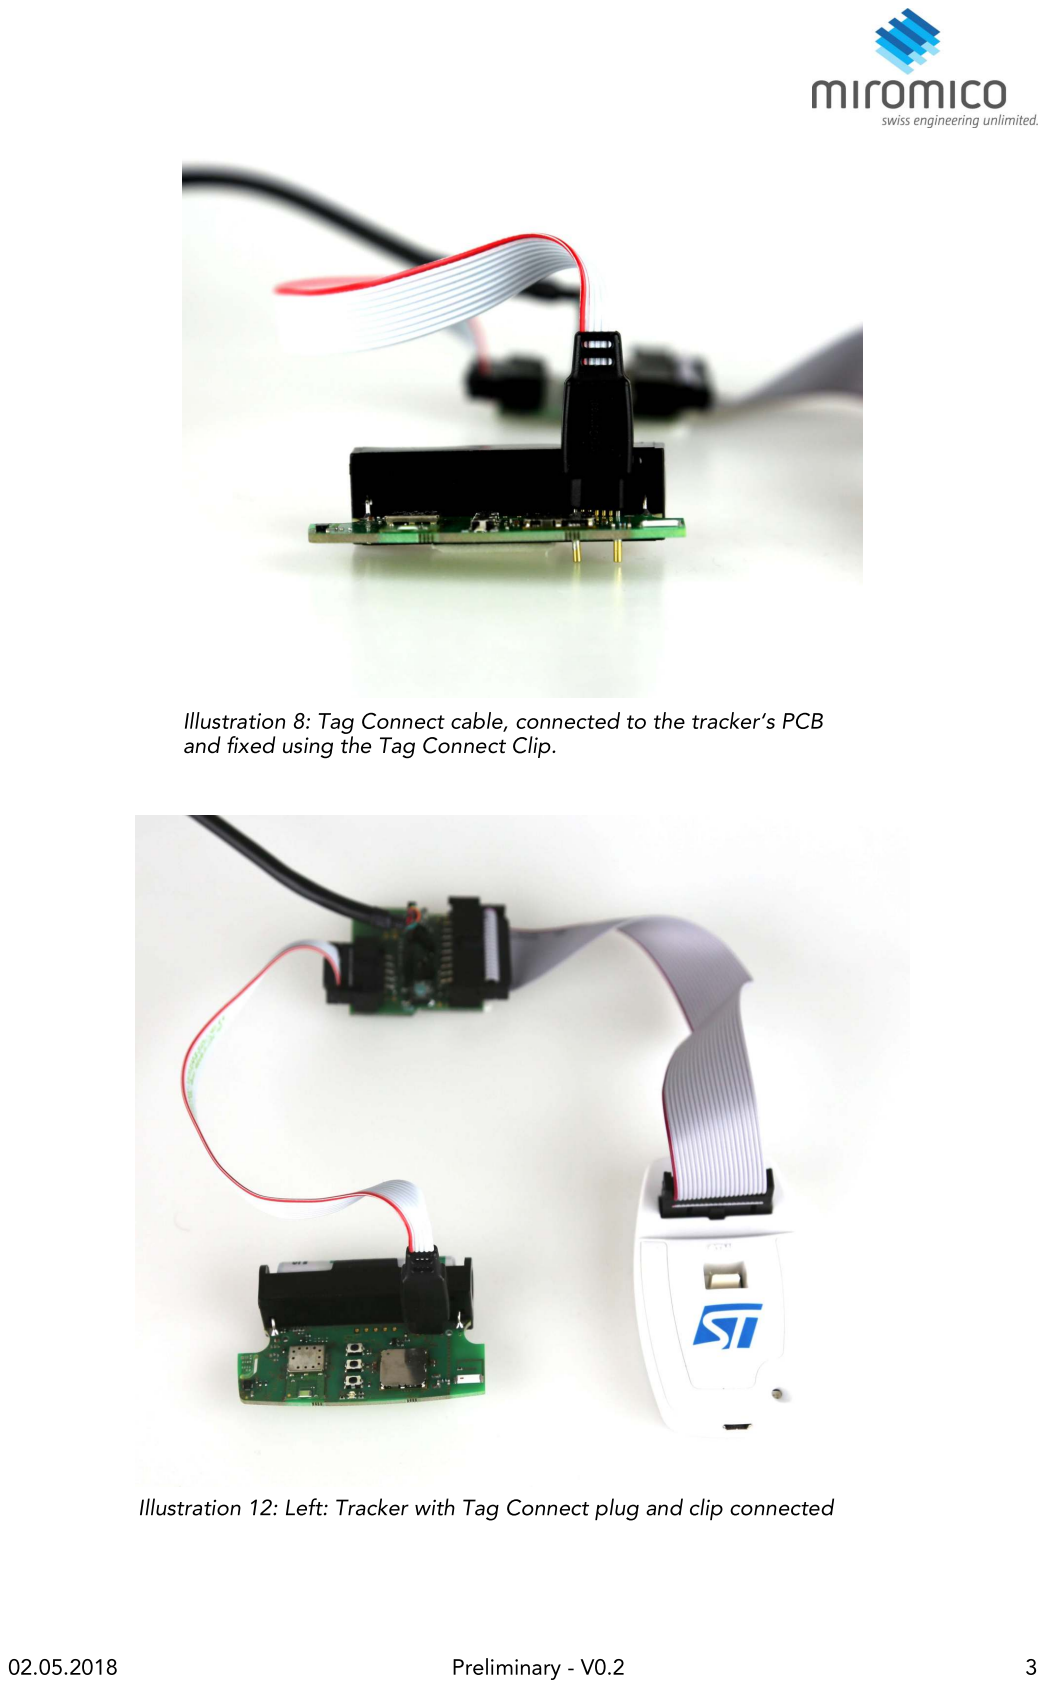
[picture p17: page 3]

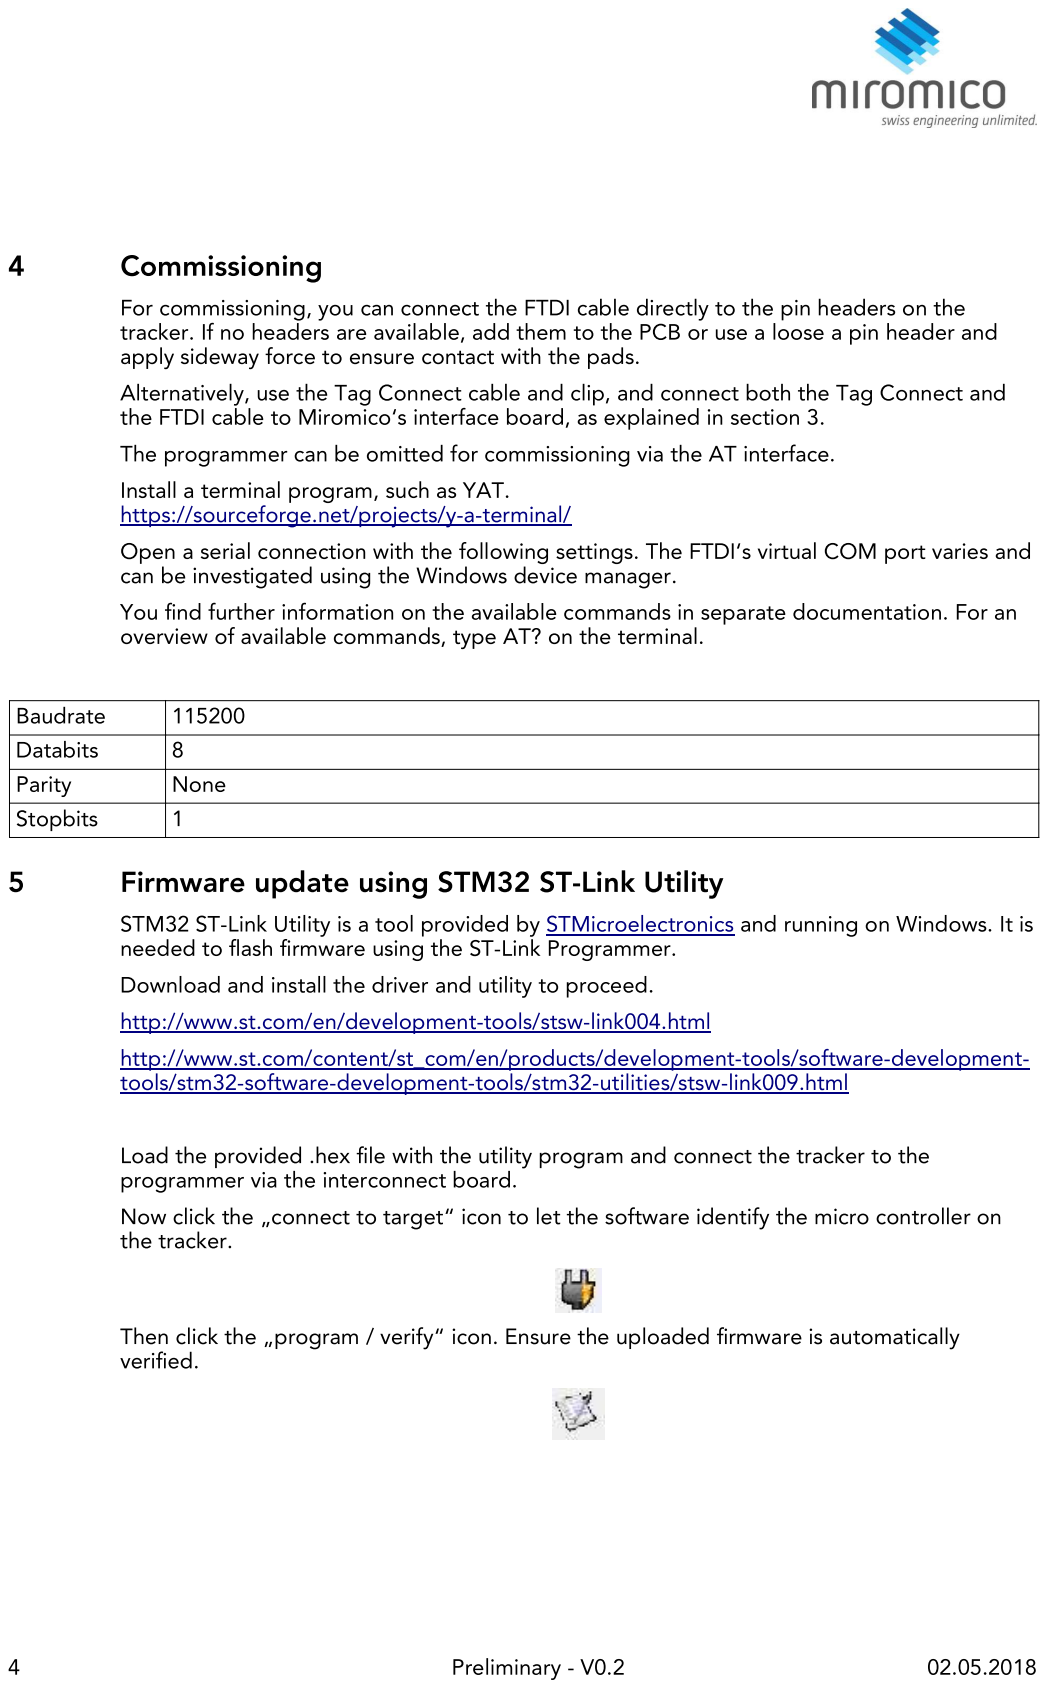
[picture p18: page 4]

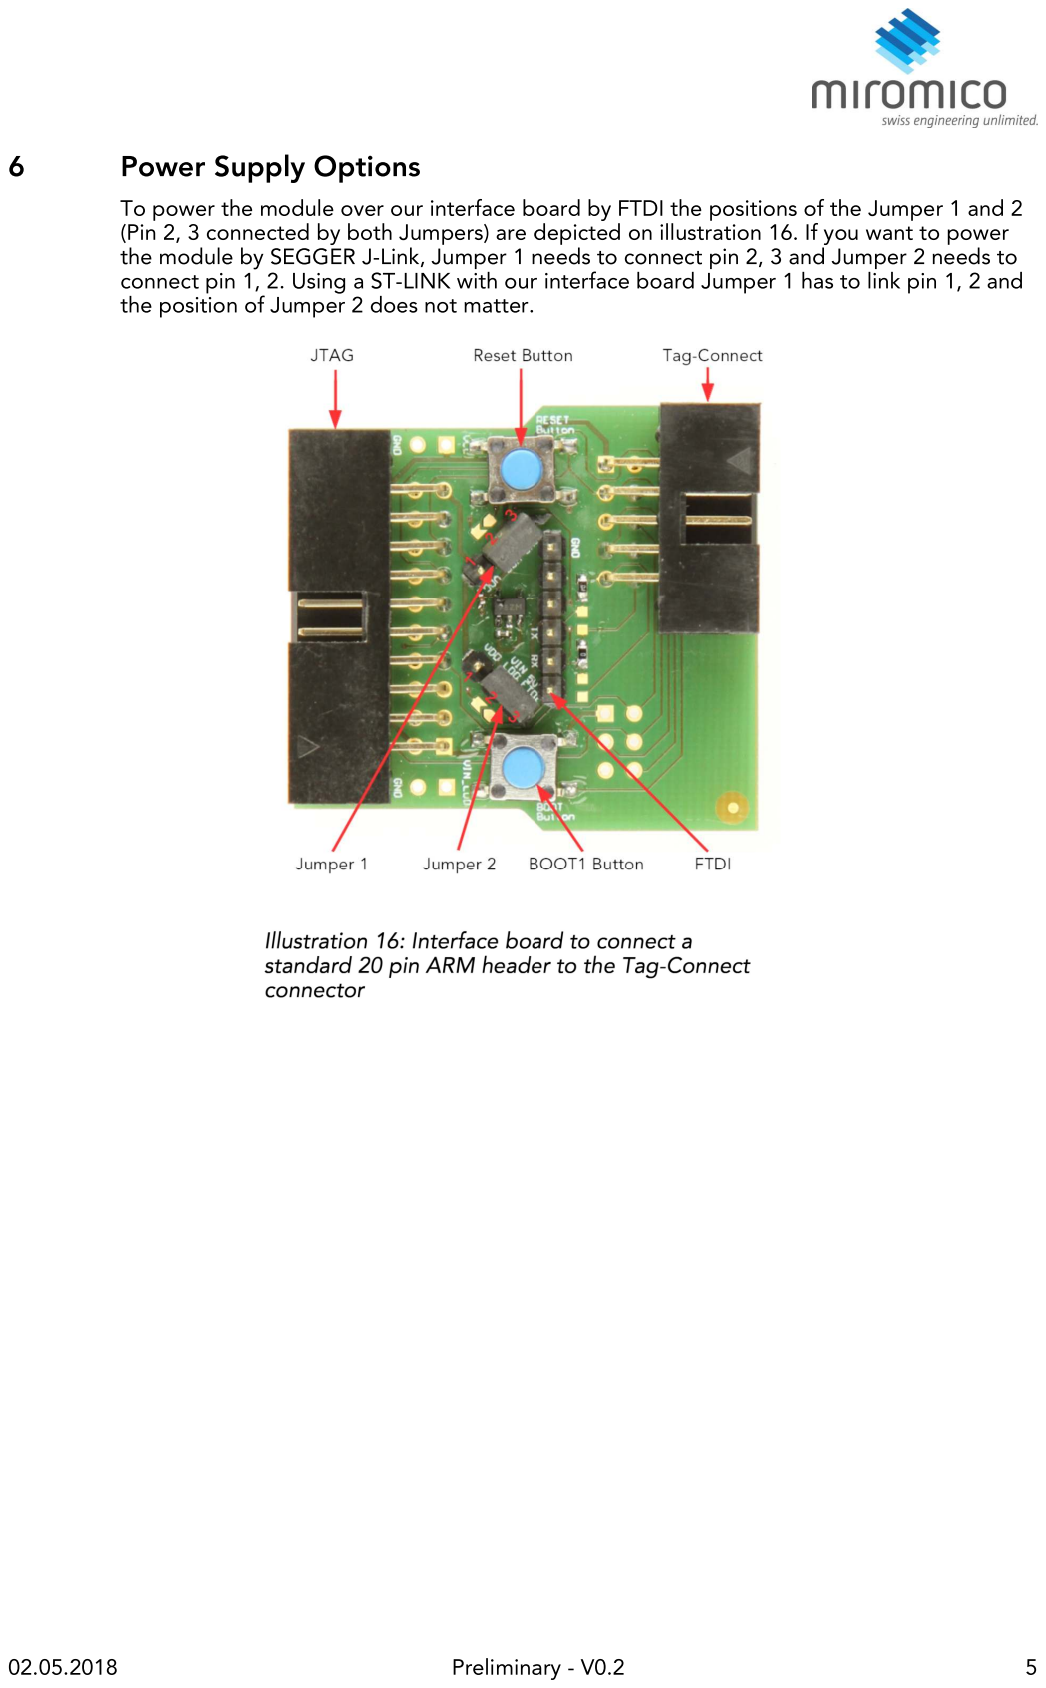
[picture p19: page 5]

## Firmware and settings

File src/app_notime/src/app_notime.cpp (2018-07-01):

/* notime main application
 * Checks orientation, temperature, humidity and proximity to other objects.
 * Alerts user with beep if some values critical.
 *
 * Done with Arduino UNO, for TTN UNO, double check ports!
 *
 * ADXL345 / Arduino UNO / TTN Leonardo
 * GND / GND / GND
 * VCC / 5V / 5V
 * CS / 5V / 5V
 * SDA / A4 / 2
 * SCL / A5 / 3
 * Note that custom accelerometer is used. I didn't get the provided one to work properly.
 *
 * DHT-11 / Arduino UNO + TTN Leonardo
 * + / 5V
 * - / GND
 * S / 7
 *
 * US100 / Arduino UNO + TTN Leonardo
 * VCC / 5V
 * GND / GND
 * Echo / 11
 * Trig / 10
 *
 * u-blox PAM-7Q + LevelShifter
 * **USE ONLY WITH LEVEL CONVERTER, 3.3V device**
 * PAM-7Q → LevelConv → TTN UNO (==TTN Leonardo)
 *                   HV  →   5V   on TTN UNO
 * VCC    →  LV  →          3.3V on TTN UNO
 * TX     →  LVx → HVx  →   TTN UNO 5
 * RX     →  LVx → HVx  →   TTN UNO 13
 * V_BCKP →  nc
 * TIMEPULSE→  nc
 * SDA    →  nc
 * SCA    →  nc
 * S0 & S1 must be bridged to the right (GND)
 *
 * Other wiring:
 * red led: + / 4 with 220R, - / GND
 * green led: + / 8 with 220R, - / GND
 * active buzzer: + / 12, - / GND with 100R
 * themistor (polarity does not matter): a / 5V, b / GND with 10kR and A3
 *
 * TODO:
 * - Take averages over time also for angle
 * - Send messages as payloads
 * - Calculate speed from GPS?
 *   - probably should do in arduino not to have to transmit data
 *
 * NicetoHaves:
 * - Translate Acceleration input to degrees (either find library or copy-paste math)
 * - Get a power supply for breadboard (6-12V)
 * - Code in other IDE
 * - Refactor, unify naming conventions
 * - Different sounds for different conditions (use tone(), noTone())
****************************************************************************/

/* ------------------- Accelerometer ADXL345 ------------------------------*/
#include <Wire.h>  //arduino IDE contains I2C library
#include <Arduino.h> // need to use Arduino files as cpp files
#include <stdio.h> // for printf

#define Register_ID 0    //Address defined ADXL345 register
#define Register_2D 0x2D
#define Register_X0 0x32
#define Register_X1 0x33
#define Register_Y0 0x34
#define Register_Y1 0x35
#define Register_Z0 0x36
#define Register_Z1 0x37

#define Reg_OFSX 0x1E     //ADXL345 correct register address definitions
#define Reg_OFSY 0x1F
#define Reg_OFSZ 0x20
#define Reg_PWR_CTL 0x2D

int ADXAddress = 0xA7>>1;  //Converted to 7 address
int reading = 0;
int val = 0;
int X0,X1,X_out;
int Y0,Y1,Y_out;
int Z1,Z0,Z_out;
double Xg,Yg,Zg;
bool use_accel = true;
float tilt_crit[2] = {0};
uint16_t XgB, YgB;

/* -------------------  DHT11 ------------------------------------*/
#include <dht11.h> // for temp + humidity
#include <RunningAverage.h> // For running averages

dht11 DHT11;
#define DHT11PIN 7

RunningAverage myRA_T(10);
RunningAverage myRA_h(10);

/* -------------------  US100 ------------------------------------*/
///*US100, ultrasound distance measurement*/
//#include <NewPing.h> // for US distance
//int echoPin = 11;
//int trigPin = 10;
//int duration, inches, cm; // vars for duration of the ping, and the distance
//NewPing sonar(trigPin, echoPin, 100); //init sonar and limit distance 100 cm

/* -------------------  Sound (+Light) Alarm ----------------------------*/
int buzzPin = 12;
int ledGreen = 8;
int ledRed = 4;

/* -------------------  GPS u-blox PAM-7Q -------------------------------*/
#include <TinyGPS++.h>
#include <AltSoftSerial.h>

TinyGPSPlus gps;
static const int RXPin = 13, TXPin = 5;
AltSoftSerial gpsSerial(RXPin, TXPin);
// init
int gps_avg_per = 3; // average over <n> measurements, report only then
int gps_counter = 0; // count measurmements with gps

RunningAverage hdops(gps_avg_per); // signal quality
RunningAverage speeds(gps_avg_per); // velocities (as calculated by gps)

uint16_t velB, distB; // velocity and distance as bytes

/* --------------------- Thermistor ---------------------------------*/
int thermistorPin = 3;
int R_therm = 10000;
float logR2, R2, tm_out0, tm_out;
// float c1 = 1.009249522e-03, c2 = 2.378405444e-04, c3 = 2.019202697e-07;

RunningAverage myRA_Tout(10);
/* ----------------------- SHT - Sensirion ------------------------- */
// #include <SHTSensor.h>

// SHTSensor sht;
// bool use_accel = false;

/* --------------------------- TTN ----------------------------------*/
#include <TheThingsNetwork.h>
#include <private_keys.h>

#define loraSerial Serial1
// #define debugSerial Serial // is needed?

// Use european freq plan
#define freqPlan TTN_FP_EU868
TheThingsNetwork ttn(loraSerial, Serial, freqPlan);
bool is_connected = false;

// construct data structure to hold our messages
// not used because TheThingsMessage does not have countrepart in js
// devicedata_t data = api_DeviceData_init_default;
uint8_t dataBuffer[16] = {0}; // uint8_t is byte
uint32_t latB, lonB; // latitude and lognitude in bytes
uint16_t tInB, tOutB; // temp in and out in bytes
#define send_per 30 //gps_per*gps_avg_per
// utility to get array size
#define COUNT_OF(array) (sizeof(array) / sizeof(array[0]))

/* -------------------  Globals ------------------------------------*/
#define us_per 1 // Define periods with which report measurements
#define accel_per 10 // how often reported
#define temp_per 10 // how often reported
#define gps_per 10 // How often is the data sampled
#define global_delay 1000
int max_per = max(max(max(gps_per, accel_per), temp_per), send_per);
int i = 0;
int num_meas = 1;
int us_thresh = 10; // <thresh> cm for alarm
float grav_thresh = 0.20; //<thresh> Xg|Yg for alarm
int th_thresh[4] = {0, 35, 20, 80}; // <thresh> Tlow, Thigh, HumLow, HumHigh for alarm
bool do_alert = false;

/* --------------- Function Declarations ------------------------------ */
/*ADXL345 GY-291 ... accelerometer*/
void setReg(int device,int reg,byte value){
  Wire.beginTransmission(device);
  Wire.write(reg);
  Wire.write(value);
  Wire.endTransmission();
}

void setAccReg(int reg,byte value){
  setReg(ADXAddress,reg,value);    //ADXAddress = 0xA7>>1
}

void add_buffer_temp(double tIn, double tOut, int it = 0) {
  // it ... pos where to start writing to the buffer

  tInB = ((tIn + 50) / 100.00) * pow(256,2);
  tOutB = ((tOut + 50) / 100.0) * pow(256,2);

  dataBuffer[it] = ( tInB >> 8 ) & 0xFF;
  dataBuffer[it+1] = tInB & 0xFF;

  dataBuffer[it+2] = ( tOutB >> 8 ) & 0xFF;
  dataBuffer[it+3] = tOutB & 0xFF;
}

void add_buffer_gps(double lat, double lon){

  latB = ((lat + 90) / 180.0) * pow(256,3);
  lonB = ((lon + 180) / 360.0) * pow(256,3);

  dataBuffer[0] = ( latB >> 16 ) & 0xFF;
  dataBuffer[1] = ( latB >> 8 ) & 0xFF;
  dataBuffer[2] = latB & 0xFF;

  dataBuffer[3] = ( lonB >> 16 ) & 0xFF;
  dataBuffer[4] = ( lonB >> 8 ) & 0xFF;
  dataBuffer[5] = lonB & 0xFF;
}

void add_buffer_dyn(float speed, float dist, int it = 0) {
  // Velocity As Bytes

  // higher precision
  // round to decimals, scale and lift to given byte precision
  velB = speed / 99.0 * pow(256,2);
  dataBuffer[it] = (velB >> 8) & 0xFF;
  dataBuffer[it+1] = (velB) & 0xFF;

  // lower precision
  // velB = (round(speed * 100.0) / 100.0);
  // dataBuffer[it] = velB;

  // Distance as Bytes
  // round to decimals, scale and lift to given byte precision
  distB = dist / 9999.0 * pow(256,2);
  dataBuffer[it+2] = (distB >> 8) & 0xFF;
  dataBuffer[it+3] = (distB) & 0xFF;
}

void add_buffer_tilt(float Xg_crit, float Yg_crit, int it = 0) {
  XgB = (Xg_crit  + 2.0) * pow(256,1) / 4;
  YgB = (Yg_crit + 2.0) * pow(256,1) / 4;

  dataBuffer[it] = XgB;
  dataBuffer[it+1] = YgB;
}

void update_accelerometer(){

  Wire.beginTransmission(ADXAddress);//Read X-axis data
    Wire.write(Register_X0);
    Wire.write(Register_X1);
    Wire.endTransmission();
    Wire.requestFrom(ADXAddress,2);
    if(Wire.available()<=2){
      X0 = Wire.read();
      X1 = Wire.read();
      X1 = X1<<8;
      X_out = X0+X1;
    }
    Wire.beginTransmission(ADXAddress);//Read y-axis data
    Wire.write(Register_Y0);
    Wire.write(Register_Y1);
    Wire.endTransmission();
    Wire.requestFrom(ADXAddress,2);
    if(Wire.available()<=2){
      Y0 = Wire.read();
      Y1 = Wire.read();
      Y1 = Y1<<8;
      Y_out = Y0+Y1;
    }
    Wire.beginTransmission(ADXAddress);//Read z-axis data
    Wire.write(Register_Z0);
    Wire.write(Register_Z1);
    Wire.endTransmission();
    Wire.requestFrom(ADXAddress,2);
    if(Wire.available()<=2){
      Z0 = Wire.read();
      Z1 = Wire.read();
      Z1 = Z1<<8;
      Z_out = Z0+Z1;
    }
    Xg = X_out/256.00;   //The output is converted to gravitational acceleration g, 2 decimal places later.
    Yg = Y_out/256.00;
    Zg = Z_out/256.00;
    // Report values ---------------------------------------------------------------
    // alarm
    if((abs(Xg)> grav_thresh) || (abs(Yg) > grav_thresh)){
      do_alert = true;
    }

    // Save Critical tilts
    if (abs(Xg) > abs(tilt_crit[0])) {
      tilt_crit[0] = Xg;
    }
    if (abs(Yg) > abs(tilt_crit[1])) {
      tilt_crit[1] = Yg;
    }

    add_buffer_tilt(tilt_crit[0], tilt_crit[1], 10);

    if(i%accel_per==0){
      Serial.print("i:");Serial.print(num_meas);
      Serial.print(":G.: X="); //So that the display text ' X ='
      Serial.print(Xg);
      Serial.print("\t Y=");
      Serial.print(Yg);
      Serial.print("\t Z=");
      Serial.println(Zg);

      Serial.print("Tilts :");
      Serial.print(tilt_crit[0]); Serial.print(", ");
      Serial.println(tilt_crit[1]);
    } // end if accel

}

void update_temphum() {
  // DHT-11
  DHT11.read(DHT11PIN);
  float hm = (float)DHT11.humidity;
  float tm = (float)DHT11.temperature + 4*(!use_accel); // hardcode correction

  // Thermistor - Ambient Temperature
  float tPin_val = analogRead(thermistorPin);
  //the formula to calculate  temperature in degC
  // R2 = R_therm * (1023.0 / tPin_val - 1.0);
  // logR2 = log(R2);
  // tm_out0 = (1.0 / (c1 + c2*logR2 + c3*logR2*logR2*logR2));
  // tm_out = tm_out0 - 273.15;
  int corr = -8; // additional connection
  int B_const = 3435; float RT_const = 25.0; // tune me
  // R2 = (1023.0*R_therm)/tPin_val-R_therm;
  // tm_out0 = B_const/(log(R2/R_therm) + B_const/(273.15+RT_const));
  // tm_out = tm_out0 - 273.15 + corr;
  float R2 = (1023.0*R_therm)/tPin_val-R_therm;
  float tm_out0 = (B_const/(log(R2/R_therm)+(B_const/(273.15+RT_const))));
  tm_out = tm_out0 - 273.15 + corr;

  // SHT -  Ambient Temperature --- not used
  // sht.readSample();
  // float tm_out = sht.getTemperature();

  // alarm
  bool ct = (tm<th_thresh[0])||(tm>th_thresh[1]);
  bool ch = (hm<th_thresh[2])||(hm>th_thresh[3]);
  if (ch || ct){
    do_alert = true;
  }
    // Running Average of Temperature
  myRA_T.addValue(tm); // Add value to buffer on each measurement
  myRA_h.addValue(hm);
  myRA_Tout.addValue(tm_out);
  // Report Values --------------------------------------------------------------
  if(i%temp_per==0){
    if (myRA_T.getCount()>=myRA_T.getSize()){ // T+h measured together, cond. on one
      // Debug
      // Serial.print("Count:");Serial.print(myRA_T.getCount());
      // Serial.print("\t Size:");Serial.println(myRA_T.getSize());

      Serial.print("RAs:\t");
      Serial.print("Hum.:");
      Serial.print(myRA_h.getAverage(), 2);
      Serial.print(" % ");
      Serial.print("\t Temp. Box: ");
      Serial.print(myRA_T.getAverage(), 2);// Print a centigrade temperature
      Serial.print(" C "); // Print the unit of the centigrade temperature
      Serial.print("\t Temp. Amb.: ");
      Serial.print(myRA_Tout.getAverage(), 2);// Print a Cdeg temperature
      Serial.println(" C "); // Print the unit
      // Add data to buffer
      add_buffer_temp(myRA_T.getAverage(), myRA_Tout.getAverage(), 6);
    }
  } // end if temp
}

int update_gps(int j) {
  // Measure only every gps_per passes through loop

  // init
  double loc[gps_avg_per][3]; // location: lat,lng,alt
  int tim[gps_avg_per][4]; // time: hr,mn,sec,csec
  unsigned long time_[gps_avg_per]; // time: millis()
  int n_sat[gps_avg_per]; // number of satellites
  // float hdops[gps_avg_per];
  // double speeds[gps_avg_per];
  // bool l_valid = false, s_valid = false, t_valid = false, h_valid = false;
  if (j==0) {
    RunningAverage hdops(gps_avg_per); // signal quality
    RunningAverage speeds(gps_avg_per); // velocities (as calculated by gps)
    speeds.clear(); hdops.clear(); // explicitly start clean on each new avgg
  }

  if (gps.location.isValid()) {
    loc[j][0] = gps.location.lat();
    loc[j][1] = gps.location.lng();
  } else {
    loc[j][0] = 00.00; loc[j][1] = 00.00;
  }

  if (gps.altitude.isValid()){
    loc[j][2] = gps.altitude.meters();
  } else {
    loc[j][2] = 00.00;
  }

  if (gps.speed.isValid()) { // else try velocity
    speeds.addValue(gps.speed.kmph()/3.6); // speed in m/s
  } else {
    speeds.addValue(99.00);
  }

  time_[j] = millis(); // get time of measurmement
  if (gps.time.isValid()) {
    tim[j][0] = gps.time.hour() + 2; // adjust for time difference
    tim[j][1] = gps.time.minute();
    tim[j][2] = gps.time.second();
    tim[j][3] = gps.time.centisecond();
  } else {
    tim[j][0] = 99; tim[j][1] = 99; tim[j][2] = 99; tim[j][3] = 99;
  }

  if (gps.hdop.isValid()){
    hdops.addValue(gps.hdop.hdop());
  } else {
    hdops.addValue(00.0);
  }

  if (gps.satellites.isValid()) {
    n_sat[j] = gps.satellites.value();
  } else {
    n_sat[j] = 99;
  }

  // Check if data is incoming
  if (millis() > 10000 && gps.charsProcessed() < 10) {
    Serial.print("Connection problem?");
  }

  // Report Values ----------------------------------------------
  // Reporting ----------------------------------------------
  // Time
  // or use <Time> library and get time from board.
  Serial.print("Time: "); // F() stores string in flash memory
  if (tim[j][0] < 10) Serial.print("0");
  Serial.print(tim[j][0]);
  Serial.print(":");
  if (tim[j][1] < 10) Serial.print("0");
  Serial.print(tim[j][1]);
  Serial.print(":");
  if (tim[j][2] < 10) Serial.print("0");
  Serial.print(tim[j][2]);
  Serial.print(".");
  if (tim[j][3] < 10) Serial.print("0");
  Serial.print(tim[j][3]);

  // Location
  Serial.print("\t Location: ");
  Serial.print(loc[j][0], 4);
  Serial.print(", ");
  Serial.print(loc[j][1], 4);
  Serial.print(" alt: ");
  Serial.print(loc[j][2], 4);

  // Signal quality,  HDOP
  Serial.print("\t HDOP: "); Serial.print(hdops.getAverage(), 2);
  Serial.print(", # Satell.: "); Serial.println(n_sat[j]);

  // Add Stuff to Buffer:
  add_buffer_gps(loc[j][0], loc[j][1]);

  if (j >= gps_avg_per-1){
    // Calculations ----------------------------------------------
    if (j >=1) { // we have at least two datapoints
      float tot_dist = 0.0;
      float speeds_[gps_avg_per-1];
      float speed_sum = 0.0;

      for (int k=1; k<=gps_avg_per-1; k++){
        // distance between two following measurmements
        float dist_ = gps.distanceBetween(loc[k-1][0], loc[k-1][1], loc[k][0], loc[k][1]);
        // time delta in seconds between two measurmenets
        // float dt_ = (tim[k-1][0] - tim[k][0])*60*60 + (tim[k-1][1] - tim[k][1])*60 +
        //             (tim[k-1][2] - tim[k][2]) + (tim[k-1][2] - tim[k][2])/100;
        float dt_ = (time_[k] - time_[k-1]) * 1000;

        speeds_[k-1] = dist_ / dt_;
        speed_sum += dist_ / dt_;
        tot_dist += dist_;
      }
      // Distance between corresponding to interval endpoints
      float dist = gps.distanceBetween(loc[0][0], loc[0][1], loc[j][0], loc[j][1]);
      // float sec_delta = (tim[j][0] - tim[k][0])*60*60 + (tim[j][1] - tim[0][1])*60 +
      //               (tim[j][2] - tim[0][2]) + (tim[j][2] - tim[0][2])/100;
      // Duration of whole avg interval
      float sec_delta = (time_[j] - time_[0])*1000;
      int speeds_size = COUNT_OF(speeds_);
      float avg_speed = speed_sum/speeds_size;
      float avg_speed2 = dist / sec_delta;

      // Sanity checks:
      if (avg_speed > 99.0|| avg_speed < 0) {
        avg_speed = 99.0;
      }
      if (avg_speed2 > 99.0 || avg_speed2 < 0) {
        avg_speed2 = 99.0;
      }
      if (dist > 9999.0 || dist < 0) {
        dist = 9999.0;
      }
      if (tot_dist > 9999.0 || tot_dist < 0) {
        tot_dist = 9999.0;
      }
      // Reporting -------------------------------------------------------
      // Speed
      Serial.print("Avg Speed:: (GPS): "); Serial.print(speeds.getAverage(), 2);
      Serial.print(", (deltas): ");Serial.print(avg_speed, 2);
      Serial.print(", (endpoints): ");Serial.println(avg_speed2, 2);

      // Distance
      Serial.print("Dist (endpts.): "); Serial.print(dist, 2);
      Serial.print(", Dist (ints.): ");Serial.print(tot_dist, 2);
      Serial.print(", No. Points: "); Serial.println(speeds_size + 1);

      add_buffer_dyn(avg_speed2, dist, 12);
    }

    j = 0; // Housekeeping
  }
  else {
    j++; // Housekeeping
  }
  return j;
}

void delay_smart(unsigned long ms) {
  // This custom version of delay() ensures that the gps object is "fed"
  unsigned long start = millis(); // Get current time from board start in ms
  do {
    // wait for data available
    while (gpsSerial.available()) {
      gps.encode(gpsSerial.read());
    }
    // wait extra if needed to fill delay
  } while (millis() - start < ms);
}

void send_ttn_message(uint8_t* data, size_t data_size, port_t prt = 1) {
    // int data_size = (int)(sizeof(data)/sizeof(data[0]));
    if(is_connected){
      ttn_response_t ret_val = ttn.sendBytes(data, data_size);// sizeof(data)
      Serial.print(":Send Stat.:"); Serial.println(ret_val);
    } else {
      Serial.print("ttn message: ");
      uint8_t i = 0;
      for (i = 0; i < data_size; i++){
        if (data[i] < 16) {
          Serial.print("0");
          Serial.print(data[i], HEX);
        } else {
          Serial.print(data[i], HEX);
        }
      }
      Serial.println("");
    }
}
//void update_us() {
//
//    if(i%us_per==0){
//      Serial.print("Ping: ");
//      Serial.print(sonar.ping_cm());
//      Serial.println("cm");
//
//      digitalWrite(ledGreen, HIGH);
//      digitalWrite(ledRed, LOW);
//      //warning
//      if(sonar.ping_cm()<us_thresh) {
//        digitalWrite(ledRed, HIGH);
//        digitalWrite(ledGreen, LOW);
//        do_alert = true;
//      }
//      //no warning
//      if(sonar.ping_cm()>=us_thresh) {
//        digitalWrite(ledGreen, HIGH);
//        digitalWrite(ledRed, LOW);
//      }
//    } // end if us
//}
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
void loop(){

  if(!do_alert){// !do_alert
    digitalWrite(buzzPin, LOW);
    //noTone(buzzPin);
    digitalWrite(ledGreen, HIGH);
    digitalWrite(ledRed, LOW);
    }

  i = 1; // while counter
  while(i<=max_per){
    do_alert = false; // reset warnings

    // Accelerometer ------------------------------------
    update_accelerometer();

    // DHT-11, temperature + humidity ----------------------------------------
    update_temphum();

    // US100, ultrasound distance ----------------------------------------------
    //update_us();

    // GPS, u-blox -----------------------------------------------------------
    if (i%gps_per == 0){
      gps_counter = update_gps(gps_counter);
    } // else leave unchaged
    // Buzzer warning -------------------------------------------------------------
    if(do_alert){
      digitalWrite(buzzPin, HIGH);
      //tone(buzzPin, 1000, 500); // freq 1000, duration 500 ms
      digitalWrite(ledGreen, LOW);
      digitalWrite(ledRed, HIGH);
    } else {
      digitalWrite(buzzPin, LOW);
      digitalWrite(ledGreen, HIGH);
      digitalWrite(ledRed, LOW);
    }

    // Messaging the TTN Application
    if (num_meas % send_per == 0){
      Serial.print("N.Meas :");Serial.print(num_meas);Serial.print("\t");
      send_ttn_message(dataBuffer, COUNT_OF(dataBuffer));
      tilt_crit[0] = 0.0; tilt_crit[1] = 0.0;
    }
    // Housekeeping --------------------------------------------------------
    delay_smart(global_delay);
    i++; // increment while counter
    num_meas++; // increment total counter
    if (num_meas>4096){
      num_meas = 1;}
  } // end while
}

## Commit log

2018-06-25 Add prototype of reading sensor data
    - temp, hum, tilt, us distance
    - add some notes to Comunications section
2018-06-28 Enable all sensors, add aggregate values
    - todo: check w/ gps
    - todo: encode messages as payloads. Send with low frequency
2018-06-28 add hw case
    [arduino_leonardo_box_h35mm_m40mm_v40_notime.scad, arduino_leonardo_box_h35mm_m40mm_v40_notime_boxx.stl, arduino_leonardo_box_h35mm_m40mm_v40_notime_deckel.stl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]
2018-07-02 add low power and I2c bus notes to readme
